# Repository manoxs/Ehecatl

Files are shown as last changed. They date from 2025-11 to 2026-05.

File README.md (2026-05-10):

# Ehécatl A Frugal Digital Wind Instrument Inspired by Aztec Cosmogony


Ehecatl (eh-HEK-ah-tl), a digital wind instrument (DWI) that integrates frugal technologies with Nahua (Aztec) cosmogony. The instrument is inspired by the ceremony of the Voladores de Papantla (Papantla Flyers), which physically enacts the Quincunx, a Mesoamerican cosmological framework representing the four cardinal directions and a central axis mundi.
These spatial concepts provide the foundation for mapping gestural performance parameters to sound modulations. Ehecatl was designed as a portable, standalone instrument embedding both control and sound synthesis. It employs the
ESP32-S3 microcontroller, an I2S DAC, low-cost sensors including an accelerometer and a magnetometer, alongside a novel custom windmill-based breath sensor designed for affordability and accessibility. Sound is generated using the M16 library’s synthesis engine, utilizing a capacitive touch interface that allows for fluid, pentatonic melodic control, translating breath and movement into a cohesive sonic landscape. This project illustrates how Indigenous epistemologies can inform the design of accessible, culturally grounded musical interfaces.

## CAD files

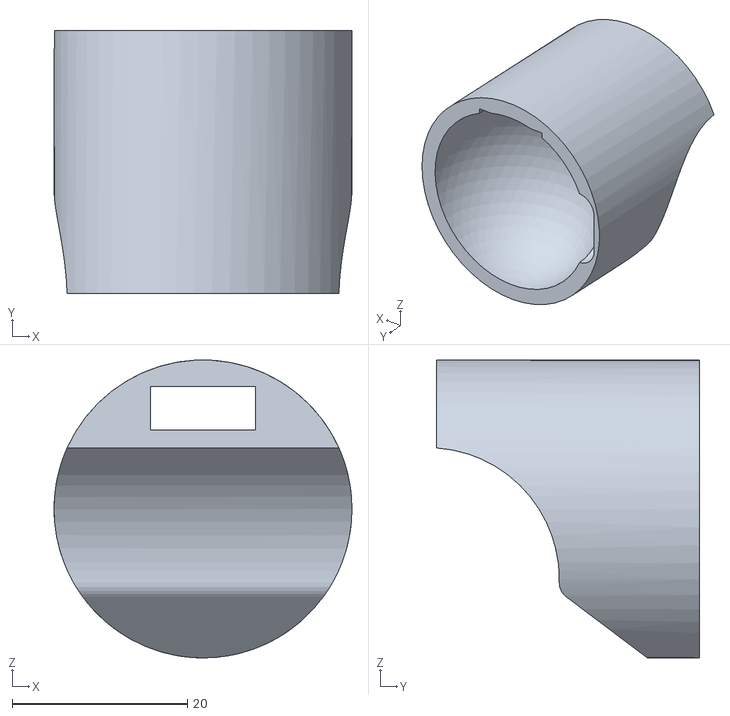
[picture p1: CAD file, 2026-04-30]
3D Print Flauta/Boquilla.stl
34.0 x 30.0 x 34.0

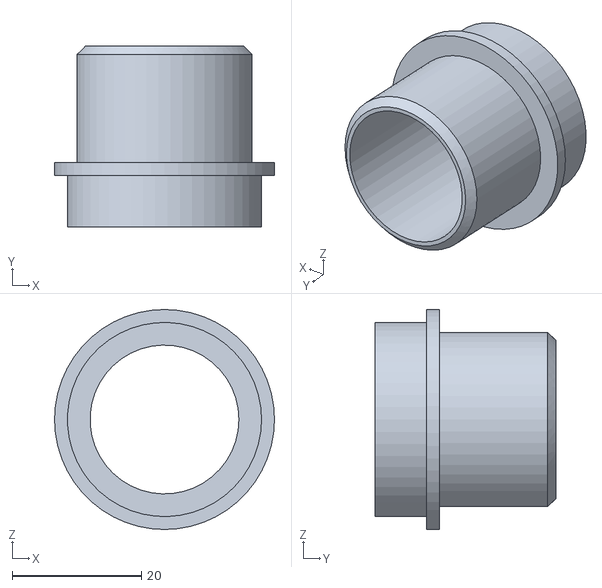
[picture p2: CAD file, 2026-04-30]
3D Print Flauta/Conector de Boquilla.stl
34.0 x 28.0 x 34.0

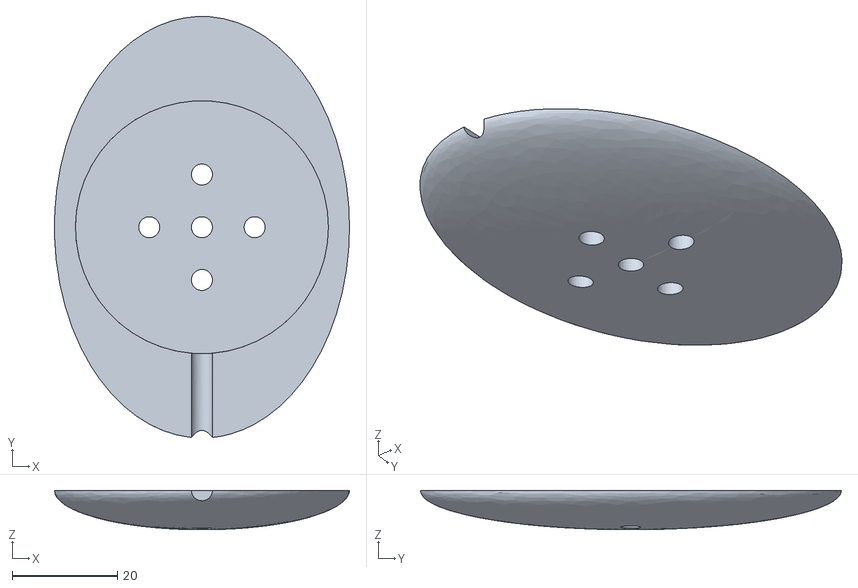
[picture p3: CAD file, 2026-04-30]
3D Print Flauta/Pluma Down.stl
56.0 x 79.9 x 7.49

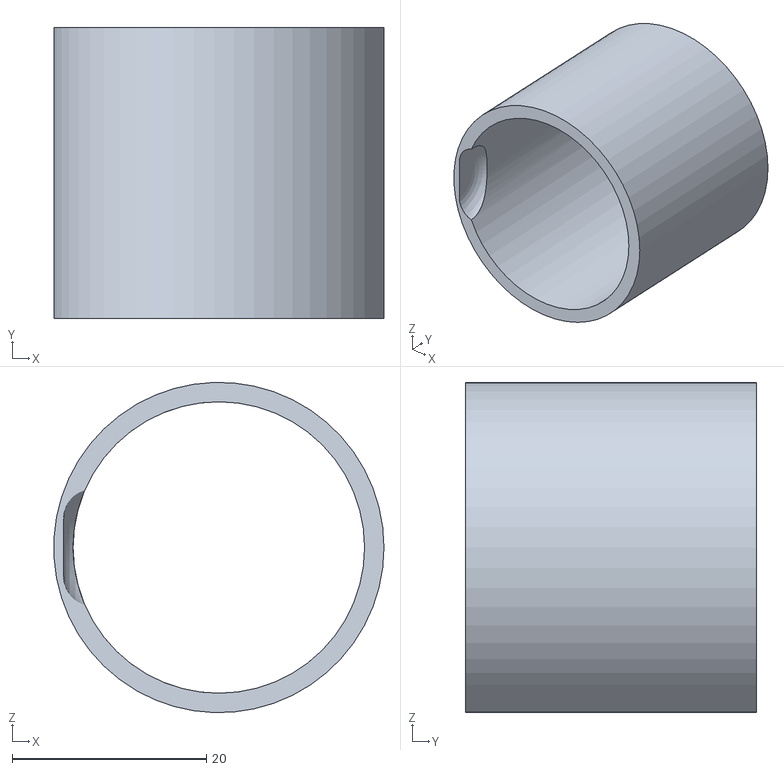
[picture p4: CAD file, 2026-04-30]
3D Print Flauta/Medio Cuerpo.stl
34.0 x 30.0 x 34.0

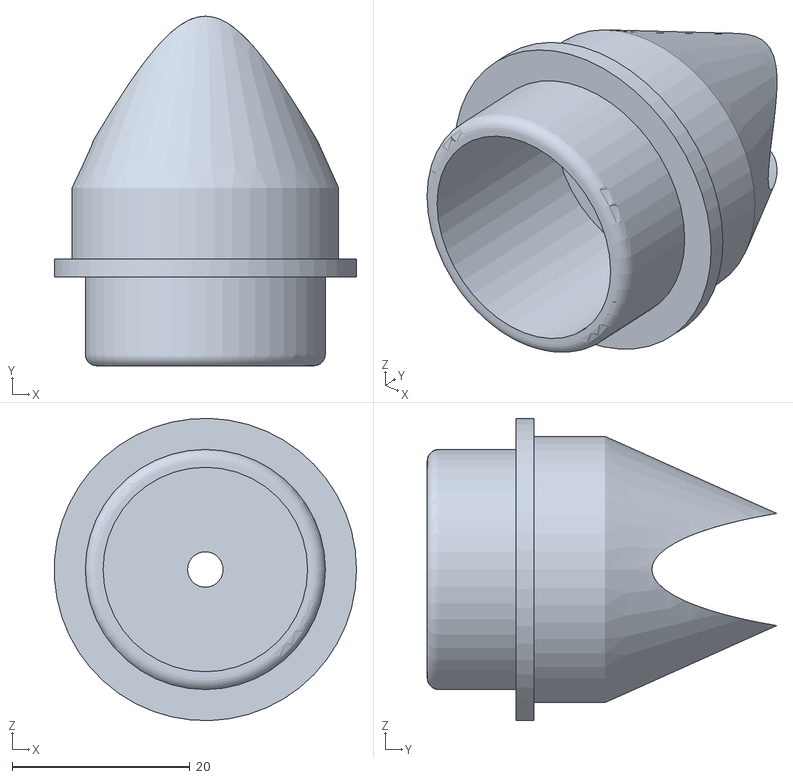
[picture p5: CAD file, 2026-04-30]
3D Print Flauta/Conector de Pluma.stl
34.0 x 39.3 x 34.0

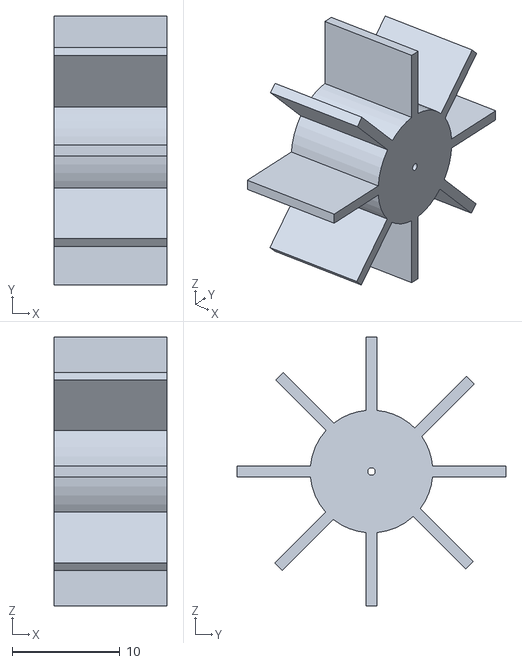
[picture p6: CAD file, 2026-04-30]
3D Print Flauta/Turbina.stl
10.5 x 25.0 x 25.0

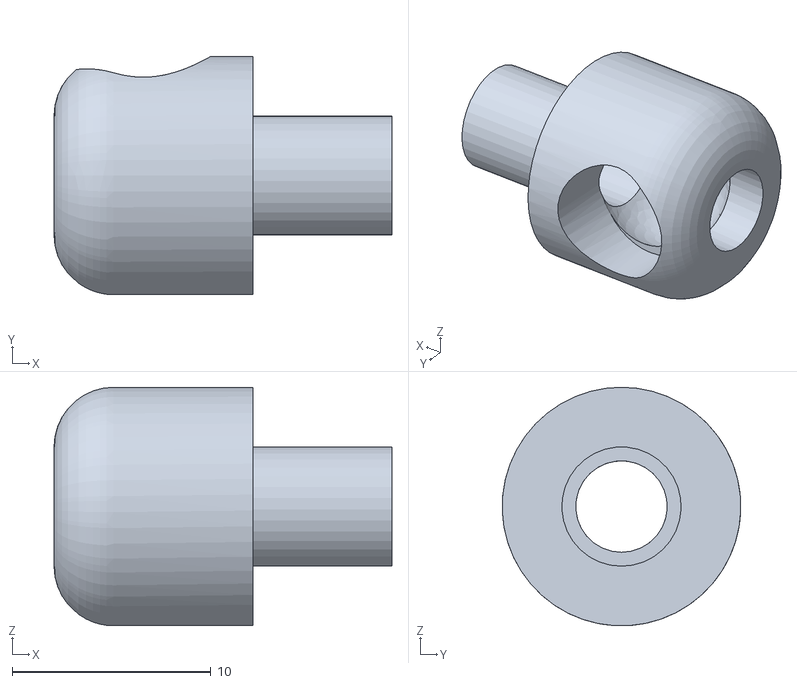
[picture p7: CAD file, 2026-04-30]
3D Print Flauta/Porta Motor.stl
17.0 x 12.0 x 12.0

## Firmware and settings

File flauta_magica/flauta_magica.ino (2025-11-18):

/*********************************************************
  Flauta Magica
**********************************************************/
// M16 Sinewave example
#include "M16.h" 
#include "Osc.h"
#include "Bob.h"

int16_t waveTable[TABLE_SIZE]; // empty wavetable
Osc aOsc1(waveTable);
Bob filter;
int16_t vol = 0; // 0 - 1024, 10 bit
unsigned long msNow = millis();
unsigned long breathTime = msNow;
unsigned long buttonTime = msNow;
int breathDelta = 5;
int buttonDelta = 30;
bool pinTouched [] = {false, false, false, false, false, false};
int pitches [] = {60, 62, 64, 67, 69, 72};
float prevAdc = 0;
bool touchingSomething = false;

#include "MultiControl.h"
MultiControl touchPin[6] {
  MultiControl(1,0),
  MultiControl(2,0),
  MultiControl(3,0),
  MultiControl(4,0),
  MultiControl(5,0),
  MultiControl(6,0)
};

#include <Adafruit_ADS1X15.h>
Adafruit_ADS1015 ads;
 
void setup() {
  Serial.begin(115200);
  delay(200);

  ads.setGain(GAIN_EIGHT);      // 8x gain   +/- 0.512V  1 bit = 0.25mV   0.015625mV
  if (!ads.begin()) {
    Serial.println("Failed to initialize ADS.");
    while (1);
  }

  Osc::sawGen(waveTable); // fill the wavetable
  aOsc1.setPitch(69);
  // seti2sPins(25, 27, 12, 21); // bck, ws, data_out, data_in // change ESP32 defaults
  audioStart();
}

void loop() {
  msNow = millis();

  if ((unsigned long)(msNow - breathTime) >= breathDelta) {
    breathTime += breathDelta;
    int16_t adc0 = ads.readADC_SingleEnded(0);
    if (!touchingSomething) adc0 = 0;
    // float adcF = min(1.0f, adc0 / 700.0f); // 0.0 - 1.0
    float adcF = (float)adc0 / 1000.0;
    adcF = min(1.0f, max(adcF, float(0.0)));
    Serial.print("adcF: "); Serial.println(adcF);
    if (abs(adcF - prevAdc) > 0.03) {
      if (adcF > prevAdc) {
        adcF = pow(adcF, 0.7);
      } else adcF = pow(adcF, 6);
    }
    adcF = slew(prevAdc, adcF, 0.2);
    filter.setCutoff(adcF); // filter cutoff
    prevAdc = adcF;
    vol =  adcF * 1024;
  }

  if ((unsigned long)(msNow - buttonTime) >= buttonDelta) {
    buttonTime += buttonDelta;
    touchingSomething = false;
    for (int i=0; i<6; i++) {
      int t = touchPin[i].isTouched();
      if (t) touchingSomething = true;
      if (t && !pinTouched[i]) {
        int pitch = pitches[i];
        aOsc1.setPitch(pitch);
        Serial.println(pitch);
        pinTouched[i] = true;
      }
      if (!t) {
        pinTouched[i] = false;
      }
    }
  }
}

/* The audioUpdate function is required in all M16 programs 
* to specify the audio sample values to be played.
* Always finish with i2s_write_samples()
*/
void audioUpdate() {
  int32_t leftVal = (aOsc1.next() * vol)>>10;
  int32_t rightVal = leftVal;
  i2s_write_samples(leftVal, rightVal);
}

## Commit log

2026-04-30 3D Print Flute
    [Boquilla.stl, Conector de Boquilla.stl, Conector de Pluma.stl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]
2026-04-30 3D print Flute files
    STL files for flute prototype
    [Boquilla.stl, Conector de Boquilla.stl, Conector de Pluma.stl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]
2026-06-02 Create .gitkeep
    add folder for schematic
2026-06-02 lines gnd
